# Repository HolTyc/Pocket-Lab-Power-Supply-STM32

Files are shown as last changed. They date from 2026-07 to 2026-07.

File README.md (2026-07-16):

# Pocket Lab Power Supply with STM32 MCU

THIS IS A FORK AND THE ORIGINAL VERSION IS HERE: https://github.com/BenMakesEverything/Pocket-Lab-Power-Supply/tree/main
A lab bench power supply, but pocket-sized and battery powered. (This repo is currently WIP)
The main MCU is STM32L031G6U6 for longer battery life.

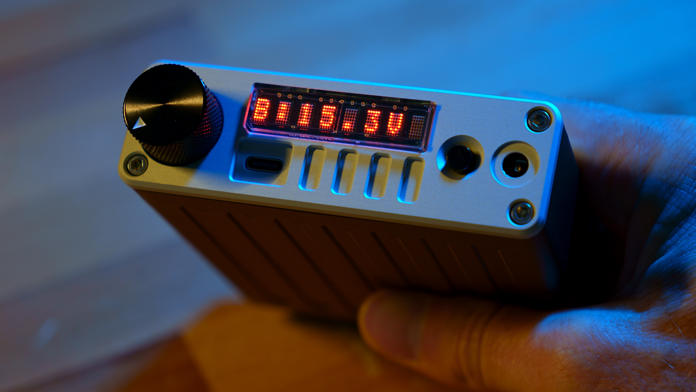
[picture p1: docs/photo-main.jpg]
Project photo


## What it is:

A 4S Lithium Ion-based Battery Bank which can act as a portable Lab-Bench Power Supply. Designed for use with 4S lithium-ion battery packs.

## Features:

- Adjustable output voltage and current limit
- Battery powered
- USB-C/PD charging
- 0.91 OLED display
- Open hardware and firmware

## Repository Structure:

- `/hardware` - PCB, schematic, BOM, Gerbers, CAD
- `/firmware` - MCU firmware and utilities
- `/docs` - build guide, diagrams, images, notes (WIP)

## Parts List

- Main PCB
- "Backpack" PCB for Display Module
- Display: HCMS-2971 or HCMS-2972 or HCMS-2973 or HCMS-2974 or HCMS-2975
- 4S 21700 Battery with integrated BMS (XH2.54mm connector) [LINK](https://www.foxbuying.com/21700-14-8v-4s1p-4500mah-rechargeable-power-lithium-battery-pack-with-customised-connetor.html)
- Faceplate
- 3D Printable Body
- 4x M3 Threaded Inserts
- 4x M3 Hex-head/socket bolts (16mm threaded portion)
- Plastic cap for button
- Encoder Knob [LINK](https://www.adafruit.com/product/5531)

## Documentation:

For common questions, see the [FAQ](docs/FAQ.md). This is a work in progress and I will add more.

The following flowchart gives an overview of the way the main components are connected.

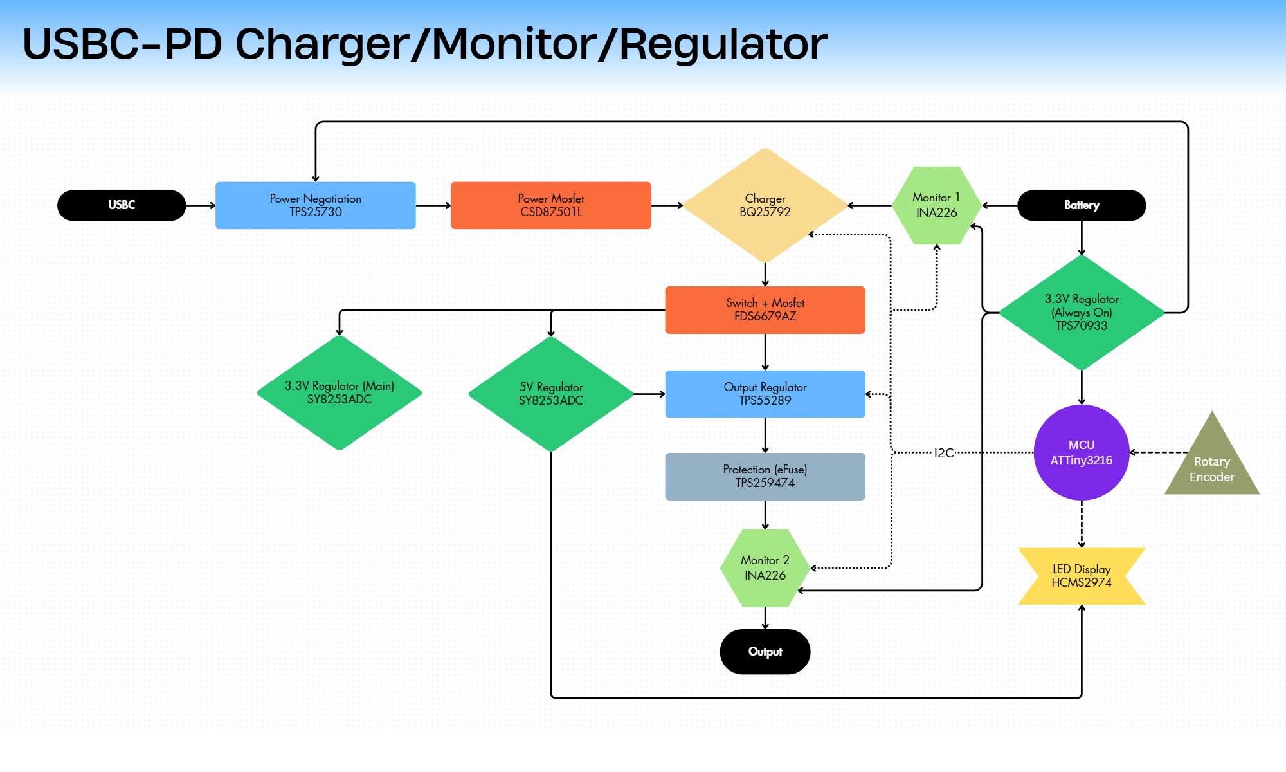
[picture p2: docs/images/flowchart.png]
Flowchart


## Safety Notice:

This project involves lithium-ion batteries and power electronics. Build and use at your own risk.

The PCB was designed for use with 4S battery packs. The BQ25792 will charge the pack up to 16.8V.

IF YOU WANT TO USE ANOTHER CELL CONFIGURATION YOU MUST CHANGE THIS! OTHERWISE THE CELLS WILL BE OVERCHARGED AND DAMAGED!

(Pin 20 "PROG" on the BQ25792 is the thing you need to adjust.)

YOU MUST USE A PACK THAT CONTAINS A BMS! THIS DESIGN DOES NOT INCLUDE ONE.

## License!

This project is licensed under the CERN Open Hardware Licence Version 2 - Strongly Reciprocal, CERN-OHL-S-2.0.

Unless otherwise stated, this applies to all hardware design files, firmware, software utilities, documentation, images, diagrams, CAD files, manufacturing files, and other project files in this repository.

Commercial use is allowed under the terms of the license. The project name, author name, logo, branding, and media identity are not licensed for use in marketing or endorsement without permission.

See `LICENSE.txt` for the full license text.

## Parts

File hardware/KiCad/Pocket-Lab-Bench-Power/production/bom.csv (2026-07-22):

Designator | Footprint | Quantity | Value | LCSC Part #
C1 | 0603 | 1 | 4.7uF/25V
C10, C7 | 0402 | 2 | 47nF
C11, C16, C17, C18, C21, C22, C23, C24, C25, C27, C28, C4 | 0805 | 12 | 10uF
C12, C37, C42, C44, C49, C5, C51, C56 | 0402 | 8 | 0.1uF
C13, C19, C20 | 0402 | 3 | 100nF
C14, C58, C6 | 0402 | 3 | 10uF
C15 | 0402 | 1 | 4.7 uF
C2, C3 | 0603 | 2 | 100nF/25V
C26, C39 | 0603 | 2 | 4.7uF
C29 | 0402 | 1 | 1nF
C30, C33, C70, C78 | 0603 | 4 | 100nF/50V
C31, C32, C34, C35, C74, C76, C80, C82 | 0603 | 8 | 22uF/10V
C36, C38 | 0603 | 2 | 10uF
C40, C45, C46, C47, C48, C50 | 0603 | 6 | 22uF
C43 | 0402 | 1 | 4.7nF
C52 | 0603 | 1 | 10u | C19702
C53, C63, C67 | 0402 | 3 | 100n | C1525
C55 | 0603 | 1 | 4.7nF
C57 | 0603 | 1 | 1uF
C60 | 1206 | 1 | 220uF | C412252
C62 | 0603 | 1 | 0.1uF
C64 | 0402 | 1 | 10n | C15195
C65, C66 | 0402 | 2 | 1u | C52923
C8, C9 | 0402 | 2 | 330pF
D2, D3 | DFN1006-2L-RD | 2 | PESD24VS1UL-N | C406227
D4 | SMB_L4.3-W3.6-LS5.4-RD | 1 | SMBJ24A_C224017 | C224017
D7 | 0603 | 1 | LED | C72038
FB1 | 0603 | 1 | FerriteBead | C1002
J1 | PinHeader_1x05_P2.54mm_Vertical | 1 | Conn_01x05_Pin
J2 | PinHeader_1x04_P2.54mm_Vertical | 1 | Conn_01x04_Pin | C2691448
J3 | Edge_Connect_6 | 1 | Conn_01x06_Pin
J4 | JST_PH_B2B-PH-K_1x02_P2.00mm_Vertical | 1 | Conn_01x02 | C495685
L1 | IND-SMD_L7.0-W6.6_MCW-0650-220 | 1 | 2.2uH | C5349701
L2, L3 | L_Sunlord_SWPA4020S | 2 | 2.2uH/4.3A | C3222957
L4 | IND-SMD_L7.5-W7.2-1 | 1 | 4.7uH | C3911513
MOSFET1 | SOIC8_751EB_ONS | 1 | FDS6679AZ | C116730
Q1 | PICOSTAR-YJG_TEX | 1 | CSD87501L | C2841784
R1, R11, R13, R37, R4, R8 | 0402 | 6 | 10K | C25744
R10 | 0603 | 1 | 30.1K 1%
R12, R15, R17, R21, R23, R25, R9 | 0603 | 7 | 0
R18 | 0603 | 1 | 21.5K/1%
R19, R38, R41 | 0603 | 3 | 4.7K/1%
R2, R33, R34 | 0402 | 3 | 10K
R28 | 0603 | 1 | 49.9K
R29, R51 | 0603 | 2 | 100K
R3 | 0603 | 1 | 100
R30, R32, R35 | 2512 | 3 | 0.01 | C840621
R31 | 0402 | 1 | 27K
R36 | 0603 | 1 | 560 1%
R5 | 0603 | 1 | 27K 1%
R57 | 0603 | 1 | 75K/1%
R58 | 0603 | 1 | 10K/1%
R6 | 0603 | 1 | 1K
R7 | 0603 | 1 | 5.23K 1%
S1 | XDCR_PEC12R-4220F-S0024 | 1 | PEC12R-4220F-S0024 | C18164805
SW1 | SW-TH_6P-L5.8-W5.8-P2.00-LS4.5-BL_1 | 1 | PS-5850A-6PL | C963201
TH1 | PinHeader_1x02_P2.54mm_Vertical | 1 | 103AT-2
TP10, TP7, TP8, TP9 | TestPoint_Pad_D1.5mm | 4 | TestPoint
U1 | WSON-6-1EP_2x2mm_P0.65mm_EP1x1.6mm | 1 | TVS2200DRV | C523793
U11 | AUDIO-TH_DC-S011A-D025-20A | 1 | DC-S011A-D025-20A | C7464915
U12 | VQFN-10_L2.0-W2.0-P0.45-TL | 1 | TPS259474ARPWR | C3662807
U13 | QFN-28_4x4mm_P0.5mm | 1 | STM32L031G6Ux | C96514
U15, U5 | TSOT-23-6 | 2 | SY8253ADC | C93736
U2 | RSM0032B-IPC_A | 1 | TPS25730SRSMR | C22390380
U3 | BQ25792 | 1 | BQ25792RQMR | C2862876
U4 | VSSOP-10_3x3mm_P0.5mm | 1 | INA226
U6 | RYQ0021A-MFG | 1 | TPS55289RYQR | C5942077
U7 | VSSOP-10_3x3mm_P0.5mm | 1 | INA226 | C49851
U8 | DMY0003A | 1 | ESD122DMYR | C1975871
U9 | DBV5_TEX | 1 | TPS70933DBVR | C89347
USB1 | USB-C-SMD_GT-USB-7051A | 1 | GT-USB-7051A | C2843970

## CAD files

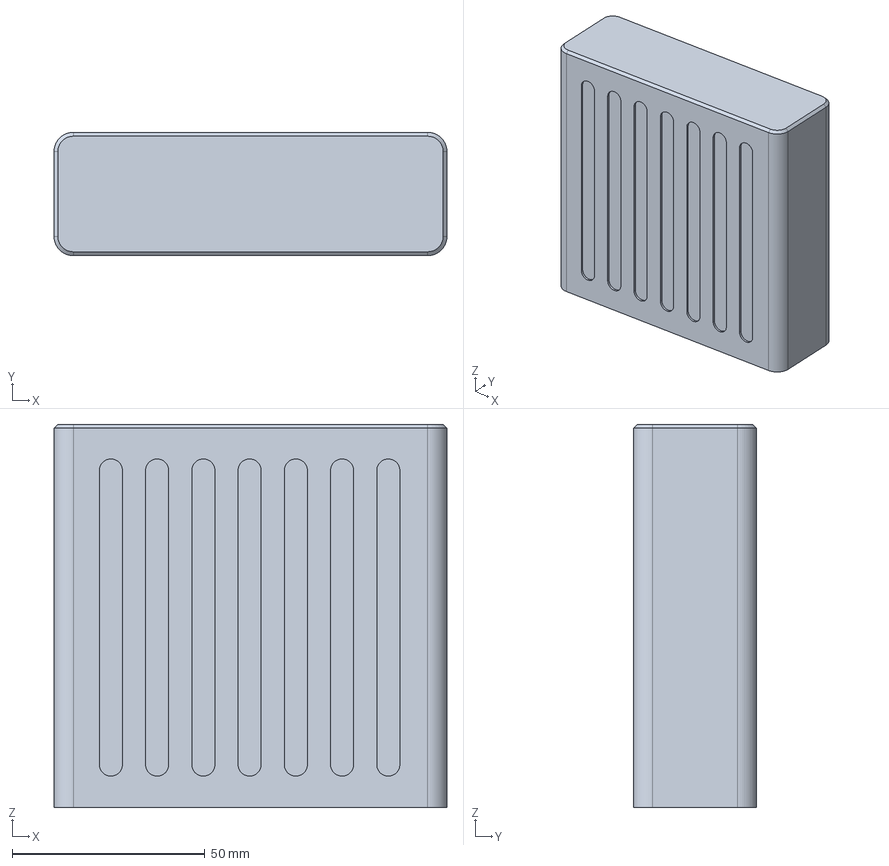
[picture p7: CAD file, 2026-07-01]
hardware/enclosure/Main-Case.step
102.0 x 32.0 x 99.5 mm

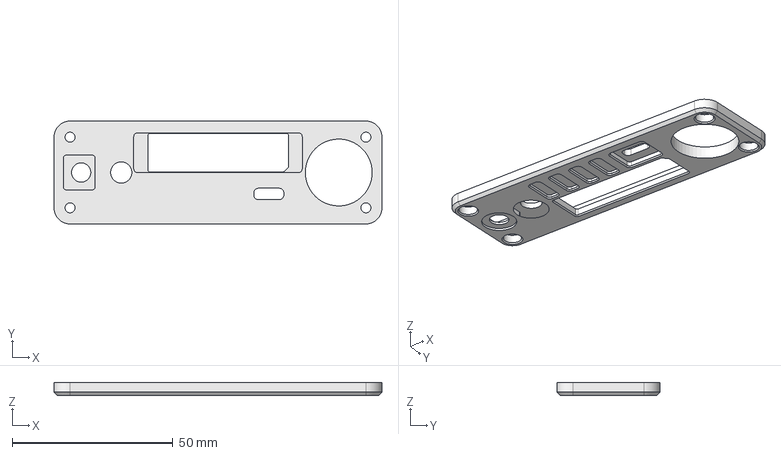
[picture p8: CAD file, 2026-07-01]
hardware/enclosure/Faceplate.step
102.0 x 32.0 x 4.00 mm

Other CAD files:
hardware/enclosure/Faceplate.stl
hardware/enclosure/Main-Case.stl

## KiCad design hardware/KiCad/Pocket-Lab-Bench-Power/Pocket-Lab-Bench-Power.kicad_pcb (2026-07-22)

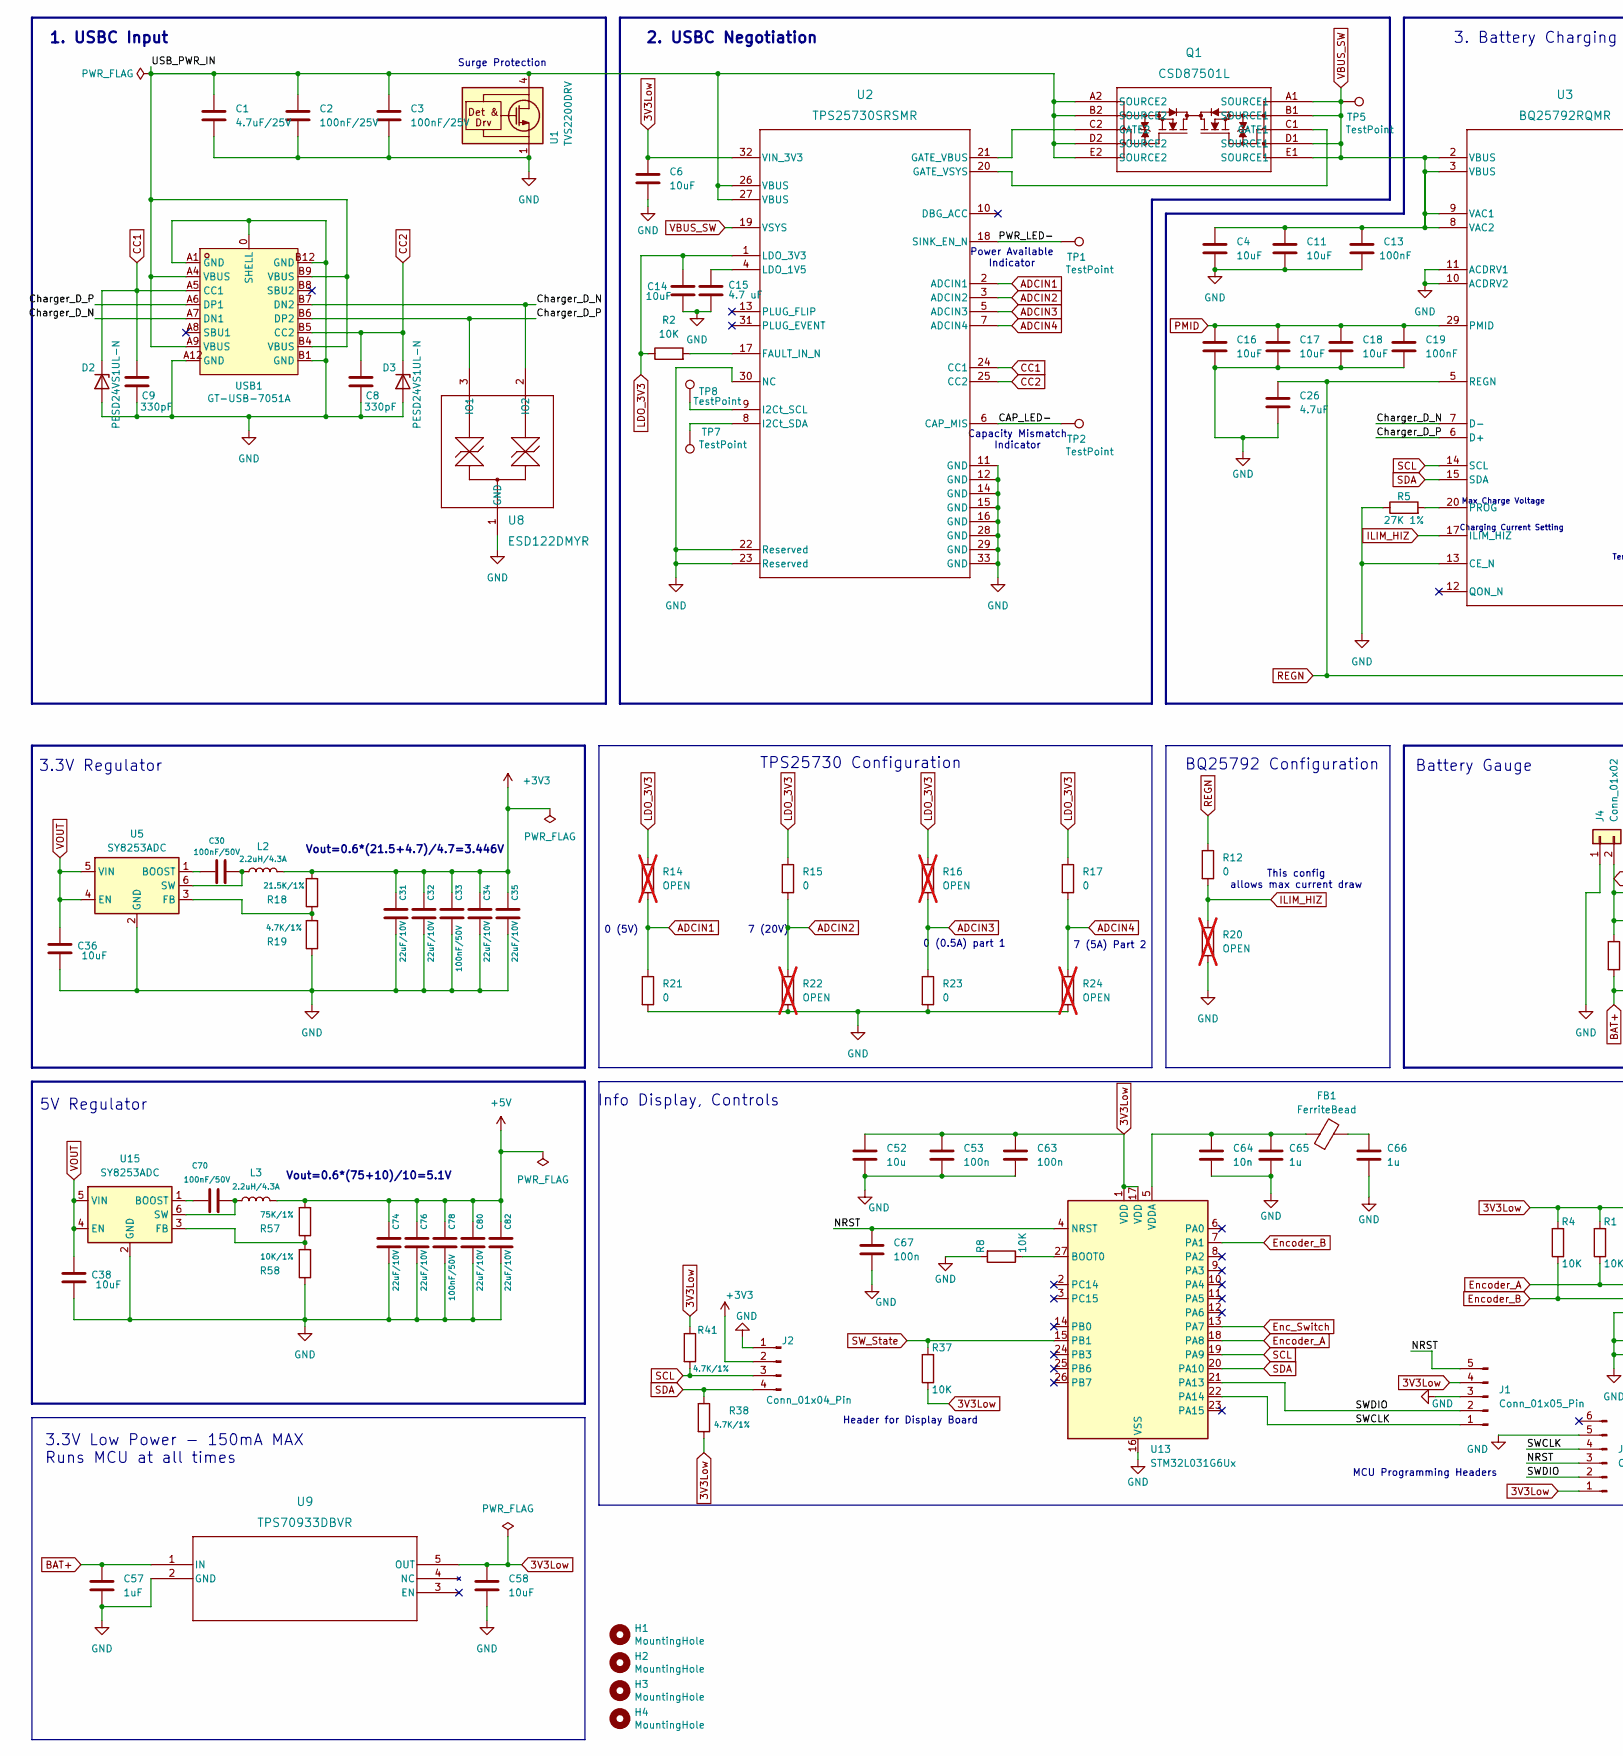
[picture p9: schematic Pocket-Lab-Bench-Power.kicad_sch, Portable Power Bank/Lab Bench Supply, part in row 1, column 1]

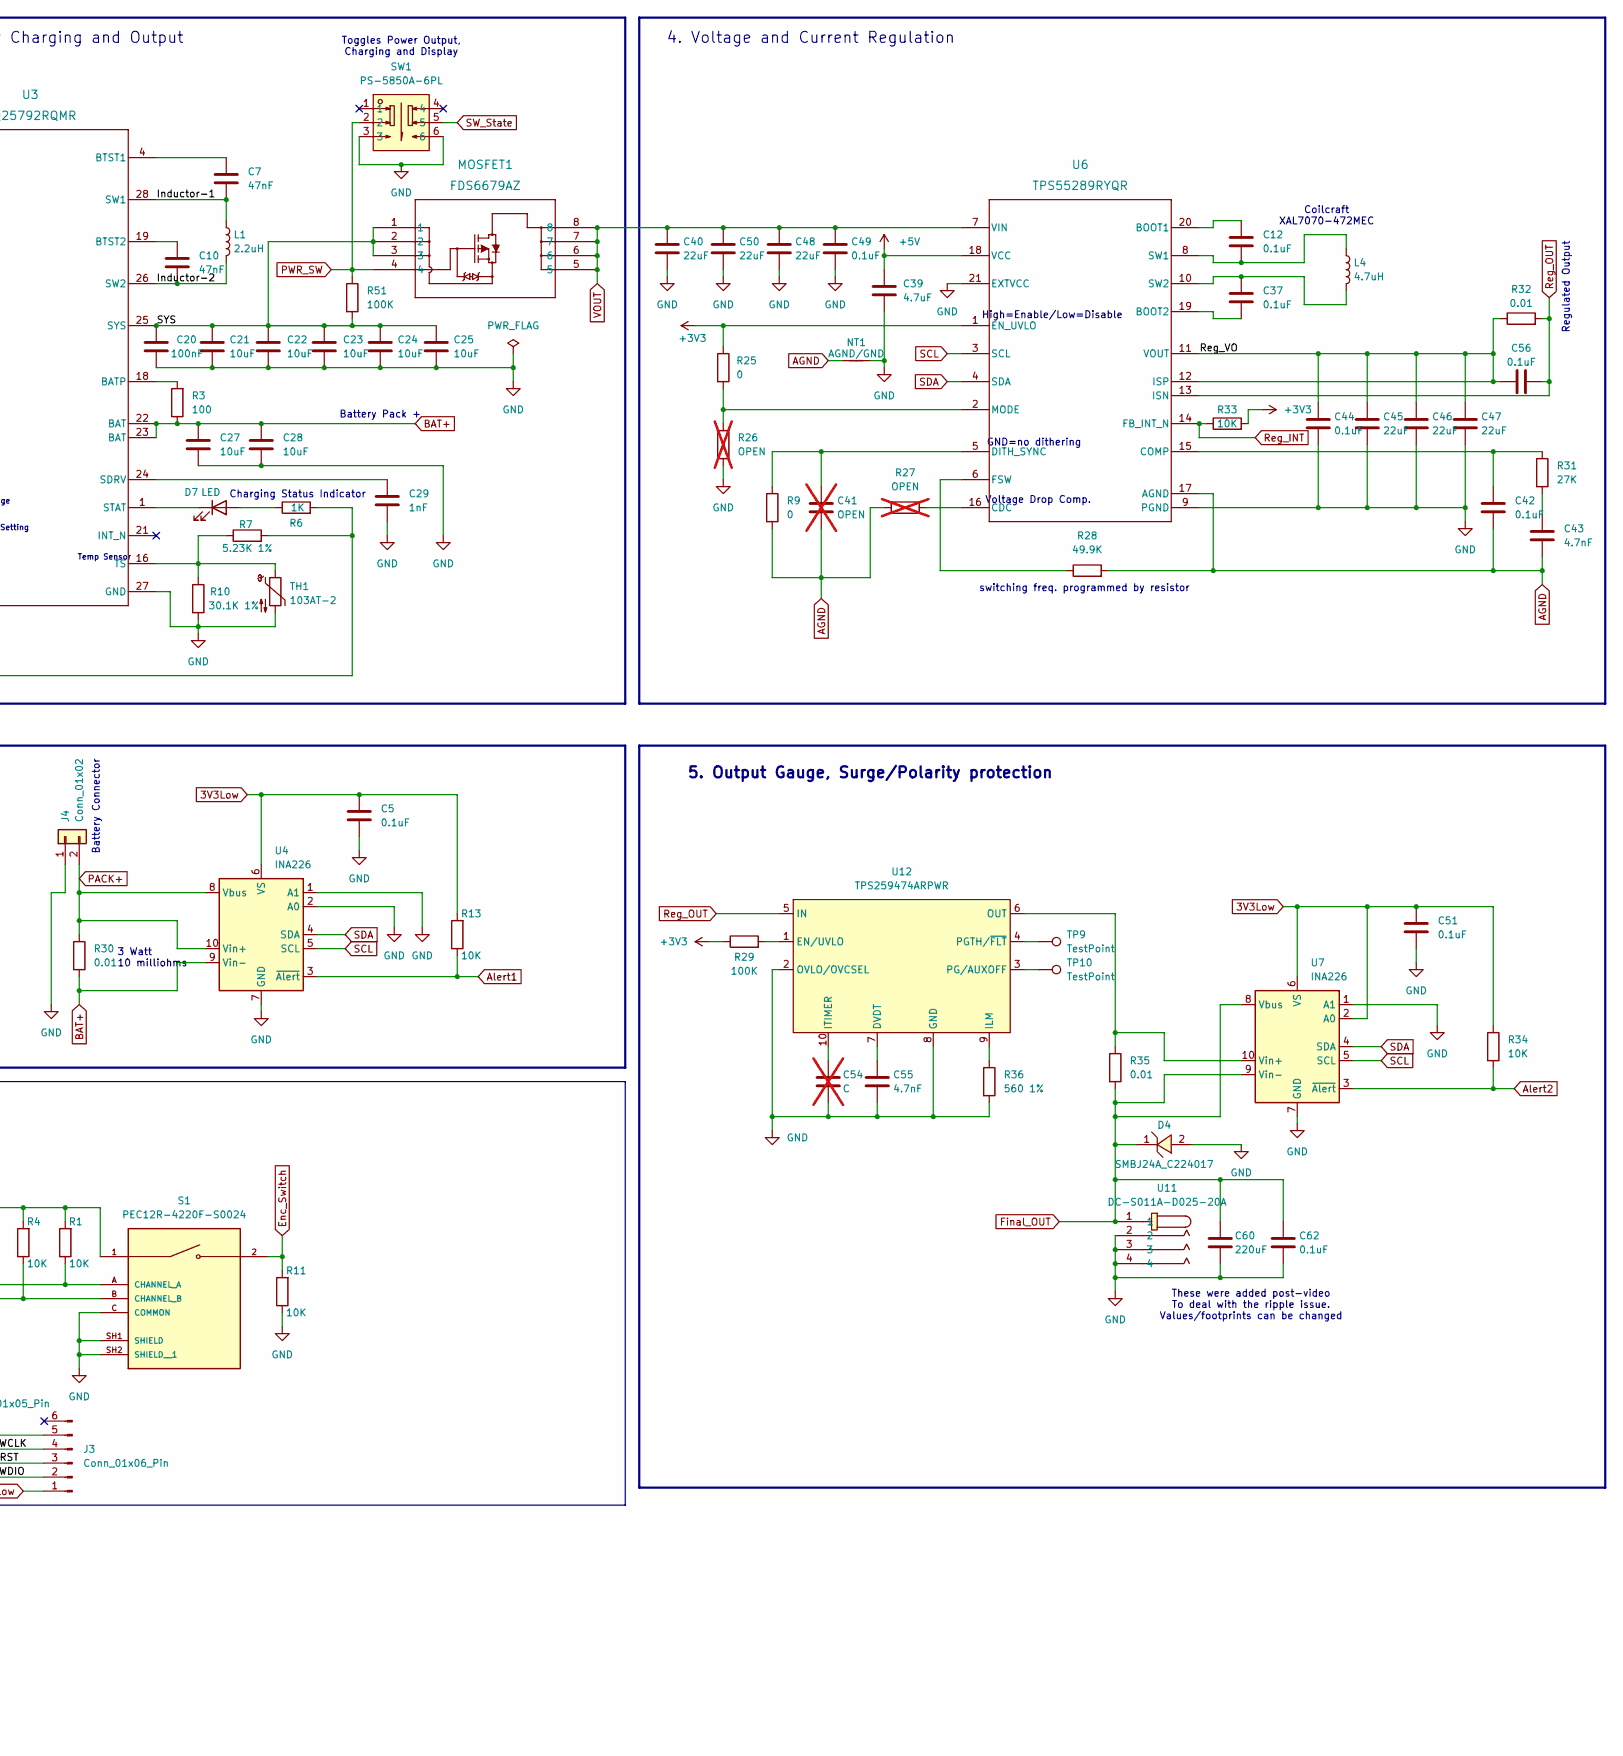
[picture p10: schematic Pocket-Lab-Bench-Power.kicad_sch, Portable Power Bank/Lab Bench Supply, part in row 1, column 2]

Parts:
C1: 4.7uF/25V; C_0603_1608Metric
C2, C3: 100nF/25V; C_0603_1608Metric
C4, C11, C16, C17, C18, C21, C22, C23, C24, C25, C27, C28: 10uF; C_0805_2012Metric
C5, C12, C37, C42, C44, C49, C51, C56: 0.1uF; C_0402_1005Metric
C6, C14, C58: 10uF; C_0402_1005Metric
C7, C10: 47nF; C_0402_1005Metric
C8, C9: 330pF; C_0402_1005Metric
C13, C19, C20: 100nF; C_0402_1005Metric
C15: 4.7 uF; C_0402_1005Metric
C26: 4.7uF; C_0603_1608Metric; Voltage Req 10V
C29: 1nF; C_0402_1005Metric
C30, C33, C70, C78: 100nF/50V; C_0603_1608Metric
C31, C32, C34, C35, C74, C76, C80, C82: 22uF/10V; C_0603_1608Metric
C36, C38: 10uF; C_0603_1608Metric
C39: 4.7uF; C_0603_1608Metric
C40, C45, C46, C47, C48, C50: 22uF; C_0603_1608Metric
C41: OPEN; C_0603_1608Metric; not fitted
C43: 4.7nF; C_0402_1005Metric
C52: 10u; C_0603_1608Metric; LCSC C19702
C53, C63, C67: 100n; C_0402_1005Metric; LCSC C1525
C54: C; C_0603_1608Metric; not fitted
C55: 4.7nF; C_0603_1608Metric
C57: 1uF; C_0603_1608Metric
C60: 220uF; C_1206_3216Metric; LCSC C412252
C62: 0.1uF; C_0603_1608Metric
C64: 10n; C_0402_1005Metric; LCSC C15195
C65, C66: 1u; C_0402_1005Metric; LCSC C52923
D2, D3: PESD24VS1UL-N; DFN1006-2L-RD; LCSC Part C406227
D4: SMBJ24A_C224017; SMB_L4.3-W3.6-LS5.4-RD; MPN SMBJ24A; LCSC Part C224017
D7: LED; LED_0603_1608Metric; LCSC Part C72038
FB1: FerriteBead; L_0603_1608Metric; LCSC C1002
H1, H2, H3, H4: MountingHole; MountingHole_3.2mm_M3
J1: Conn_01x05_Pin; PinHeader_1x05_P2.54mm_Vertical
J2: Conn_01x04_Pin; PinHeader_1x04_P2.54mm_Vertical; LCSC Part C2691448
J3: Conn_01x06_Pin; Edge_Connect_6
J4: Conn_01x02; JST_PH_B2B-PH-K_1x02_P2.00mm_Vertical; LCSC Part C495685
L1: 2.2uH; IND-SMD_L7.0-W6.6_MCW-0650-220; LCSC Part C5349701
L2, L3: 2.2uH/4.3A; L_Sunlord_SWPA4020S; LCSC Part C3222957
L4: 4.7uH; IND-SMD_L7.5-W7.2-1; LCSC Part C3911513
MOSFET1: FDS6679AZ; SOIC8_751EB_ONS; LCSC Part C116730
NT1: AGND/GND; NetTie-2_SMD_Pad0.5mm
Q1: CSD87501L; PICOSTAR-YJG_TEX; LCSC Part C2841784
R1, R4, R8, R11, R13, R37: 10K; R_0402_1005Metric; LCSC C25744
R2, R33, R34: 10K; R_0402_1005Metric
R3: 100; R_0603_1608Metric
R5: 27K 1%; R_0603_1608Metric
R6: 1K; R_0603_1608Metric
R7: 5.23K 1%; R_0603_1608Metric
R9, R12, R15, R17, R21, R23, R25: 0; R_0603_1608Metric
R10: 30.1K 1%; R_0603_1608Metric
R14, R16, R20, R22, R24, R26, R27: OPEN; R_0603_1608Metric; not fitted
R18: 21.5K/1%; R_0603_1608Metric
R19, R38, R41: 4.7K/1%; R_0603_1608Metric
R28: 49.9K; R_0603_1608Metric
R29, R51: 100K; R_0603_1608Metric
R30, R32, R35: 0.01; R_2512_6332Metric; LCSC Part C840621
R31: 27K; R_0402_1005Metric
R36: 560 1%; R_0603_1608Metric
R57: 75K/1%; R_0603_1608Metric
R58: 10K/1%; R_0603_1608Metric
S1: PEC12R-4220F-S0024; XDCR_PEC12R-4220F-S0024; PARTREV 07/21; LCSC Part C18164805
SW1: PS-5850A-6PL; SW-TH_6P-L5.8-W5.8-P2.00-LS4.5-BL_1; MPN PS-5850A-6PL; LCSC Part C963201
TH1: 103AT-2; PinHeader_1x02_P2.54mm_Vertical
TP1, TP2, TP5, TP7, TP8, TP9, TP10: TestPoint; TestPoint_Pad_D1.5mm
U1: TVS2200DRV; WSON-6-1EP_2x2mm_P0.65mm_EP1x1.6mm; LCSC Part C523793
U2: TPS25730SRSMR; RSM0032B-IPC_A; LCSC Part C22390380
U3: BQ25792RQMR; BQ25792; LCSC Part C2862876
U4: INA226; VSSOP-10_3x3mm_P0.5mm
U5, U15: SY8253ADC; TSOT-23-6; LCSC Part C93736
U6: TPS55289RYQR; RYQ0021A-MFG; LCSC Part C5942077
U7: INA226; VSSOP-10_3x3mm_P0.5mm; LCSC Part C49851
U8: ESD122DMYR; DMY0003A; LCSC Part C1975871
U9: TPS70933DBVR; DBV5_TEX; LCSC Part C89347
U11: DC-S011A-D025-20A; AUDIO-TH_DC-S011A-D025-20A; MPN DC-S011A-D025-20A; LCSC Part C7464915
U12: TPS259474ARPWR; VQFN-10_L2.0-W2.0-P0.45-TL; MPN TPS259474ARPWR; LCSC Part C3662807
U13: STM32L031G6Ux; QFN-28_4x4mm_P0.5mm; LCSC C96514
USB1: GT-USB-7051A; USB-C-SMD_GT-USB-7051A; MPN GT-USB-7051A; LCSC Part C2843970

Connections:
3V3Low: C5.1, C6.1, C51.1, C52.1, C53.1, C58.1, C63.1, J1.4, J3.1, R1.2, R4.2, R13.2, R34.1, R37.1, R38.2, R41.1, S1.1, U2.32 (VIN_3V3), U4.6 (VS), U7.2 (A0), U7.6 (VS), U9.5 (OUT), U13.1 (VDD), U13.17 (VDD)
+3V3: C31.2, C32.2, C33.1, C34.2, C35.2, J2.2, L2.2, R18.2, R25.1, R29.1, R33.2, U6.1 (EN_UVLO)
+5V: C39.1, C74.2, C76.2, C78.1, C80.2, C82.2, L3.2, R57.2, U6.18 (VCC)
/CAP_LED-: TP2.1 (1_1), U2.6 (CAP_MIS)
/Charger_D_N: U3.7 (D-), U8.2 (IO2), USB1.A7 (DN1), USB1.B7 (DN2)
/Charger_D_P: U3.6 (D+), U8.3 (IO1), USB1.A6 (DP1), USB1.B6 (DP2)
/Inductor-1: C7.2, L1.1, U3.28 (SW1)
/Inductor-2: C10.2, L1.2, U3.26 (SW2)
/NRST: C67.1, J1.5, J3.3, U13.4 (NRST)
/PWR_LED-: TP1.1 (1_1), U2.18 (SINK_EN_N)
/Reg_VO: C44.1, C45.1, C46.1, C47.1, C56.1, R32.1, U6.11 (VOUT), U6.12 (ISP)
/SWCLK: J1.1, J3.4, U13.22 (PA14)
/SWDIO: J1.2, J3.2, U13.21 (PA13)
/SYS: C20.1, C21.1, C22.1, C23.1, C24.1, C25.1, MOSFET1.1, MOSFET1.2, MOSFET1.3, R51.2, U3.25 (SYS)
/USB_PWR_IN: C1.1, C2.1, C3.1, Q1.A2 (SOURCE2), Q1.B2 (SOURCE2), Q1.D2 (SOURCE2), Q1.E2 (SOURCE2), U1.4 (IN), U1.5 (IN), U1.6 (IN), U2.26 (VBUS), U2.27 (VBUS), USB1.A4 (VBUS), USB1.A9 (VBUS), USB1.B4 (VBUS), USB1.B9 (VBUS)
ADCIN1: R14.2, R21.1, U2.2 (ADCIN1)
ADCIN2: R15.2, R22.1, U2.3 (ADCIN2)
ADCIN3: R16.2, R23.1, U2.5 (ADCIN3)
ADCIN4: R17.2, R24.1, U2.7 (ADCIN4)
AGND: C41.2, C42.2, C43.2, NT1.1, R9.2, R27.1, R28.2, U6.17 (AGND)
Alert1: R13.1, U4.3 (~Alert)
Alert2: R34.2, U7.3 (~Alert)
BAT+: C27.1, C28.1, C57.1, R3.1, R30.2, U3.22 (BAT), U3.23 (BAT), U4.9 (Vin-), U9.1 (IN)
CC1: C9.1, D2.1 (K), U2.24 (CC1), USB1.A5 (CC1)
CC2: C8.1, D3.1 (K), U2.25 (CC2), USB1.B5 (CC2)
Enc_Switch: R11.2, S1.2, U13.13 (PA7)
Encoder_A: R1.1, S1.A (CHANNEL_A), U13.18 (PA8)
Encoder_B: R4.1, S1.B (CHANNEL_B), U13.7 (PA1)
Final_OUT: C60.1, C62.1, D4.1, R35.2, U7.8 (Vbus), U7.9 (Vin-), U11.1
GND: C1.2, C2.2, C3.2, C4.1, C5.2, C6.2, C8.2, C9.2, C11.1, C13.2, C14.2, C15.2, C16.2, C17.2, C18.1, C19.2, C20.2, C21.2, C22.2, C23.2, C24.2, C25.2, C26.2, C27.2, C28.2, C29.2, C31.1, C32.1, C33.2, C34.1, C35.1, C36.2, C38.2, C39.2, C40.2, C44.2, C45.2, C46.2, C47.2, C48.2, C49.2, C50.2, C51.2, C52.2, C53.2, C54.2, C55.2, C57.2, C58.2, C60.2, C62.2, C63.2, C64.2, C65.1, C66.1, C67.2, C74.1, C76.1, C78.2, C80.1, C82.1, D2.2 (A), D3.2 (A), D4.2, J1.3, J2.1, J3.5, J4.1, NT1.2, R5.1, R8.2, R10.2, R11.1, R19.1, R20.2, R21.2, R22.2, R23.2, R24.2, R26.2, R36.2, R58.1, S1.C (COMMON), S1.SH1 (SHIELD), S1.SH2 (SHIELD__1), SW1.3, SW1.6, TH1.2, U1.1 (GND), U1.2 (GND), U1.3 (GND), U1.7 (GND), U2.11 (GND), U2.12 (GND), U2.14 (GND), U2.15 (GND), U2.16 (GND), U2.22 (Reserved), U2.23 (Reserved), U2.28 (GND), U2.29 (GND), U2.30 (NC), U2.33 (GND), U3.10 (ACDRV2), U3.11 (ACDRV1), U3.13 (CE_N), U3.27 (GND), U4.1 (A1), U4.2 (A0), U4.7 (GND), U5.2 (GND), U6.9 (PGND), U6.21 (EXTVCC), U7.1 (A1), U7.7 (GND), U8.1 (GND), U9.2 (GND), U11.2, U11.3, U11.4, U12.2 (OVLO/OVCSEL), U12.8 (GND), U13.16 (VSS), U13.28 (VSS), U15.2 (GND), USB1.0 (SHELL), USB1.A1 (GND), USB1.A12 (GND), USB1.B1 (GND), USB1.B12 (GND)
ILIM_HIZ: R12.2, R20.1, U3.17 (ILIM_HIZ)
LDO_3V3: C14.1, R2.1, R14.1, R15.1, R16.1, R17.1, U2.1 (LDO_3V3)
unnamed: C43.1, R31.2
unnamed: C66.2, FB1.2
unnamed: D7.2 (A), R6.1
unnamed: D7.1 (K), U3.1 (STAT)
unnamed: Q1.C1 (GATE1), U2.20 (GATE_VSYS)
unnamed: Q1.C2 (GATE2), U2.21 (GATE_VBUS)
unnamed: R2.2, U2.17 (FAULT_IN_N)
unnamed: TP8.1 (1_1), U2.9 (I2Ct_SCL)
unnamed: TP7.1 (1_1), U2.8 (I2Ct_SDA)
unnamed: C15.1, U2.4 (LDO_1V5)
unnamed: R3.2, U3.18 (BATP)
unnamed: C7.1, U3.4 (BTST1)
unnamed: C10.1, U3.19 (BTST2)
unnamed: R5.2, U3.20 (PROG)
unnamed: C29.1, U3.24 (SDRV)
unnamed: R7.1, R10.1, TH1.1, U3.16 (TS)
unnamed: C30.2, U5.1 (BOOST)
unnamed: R18.1, R19.2, U5.3 (FB)
unnamed: C30.1, L2.1, U5.6 (SW)
unnamed: C12.1, U6.20 (BOOT1)
unnamed: C37.2, U6.19 (BOOT2)
unnamed: R27.2, U6.16 (CDC)
unnamed: C42.1, R31.1, U6.15 (COMP)
unnamed: C41.1, R9.1, U6.5 (DITH_SYNC)
unnamed: R28.1, U6.6 (FSW)
unnamed: R25.2, R26.1, U6.2 (MODE)
unnamed: C12.2, L4.1, U6.8 (SW1)
unnamed: C37.1, L4.2, U6.10 (SW2)
unnamed: C55.1, U12.7 (DVDT)
unnamed: R29.2, U12.1 (EN/UVLO)
unnamed: R36.1, U12.9 (ILM)
unnamed: C54.1, U12.10 (ITIMER)
unnamed: R35.1, U7.10 (Vin+), U12.6 (OUT)
unnamed: TP9.1 (1_1), U12.4 (PGTH/~FLT)
unnamed: TP10.1 (1_1), U12.3 (PG/AUXOFF)
unnamed: R8.1, U13.27 (BOOT0)
unnamed: C64.1, C65.2, FB1.1, U13.5 (VDDA)
unnamed: C70.2, U15.1 (BOOST)
unnamed: R57.1, R58.2, U15.3 (FB)
unnamed: C70.1, L3.1, U15.6 (SW)
PACK+: J4.2, R30.1, U4.8 (Vbus), U4.10 (Vin+)
PMID: C16.1, C17.1, C18.2, C19.1, U3.29 (PMID)
PWR_SW: MOSFET1.4, R51.1, SW1.2
REGN: C26.1, R6.2, R7.2, R12.1, U3.5 (REGN)
Reg_INT: R33.1, U6.14 (FB_INT_N)
Reg_OUT: C56.2, R32.2, U6.13 (ISN), U12.5 (IN)
SCL: J2.3, R41.2, U3.14 (SCL), U4.5 (SCL), U6.3 (SCL), U7.5 (SCL), U13.19 (PA9)
SDA: J2.4, R38.1, U3.15 (SDA), U4.4 (SDA), U6.4 (SDA), U7.4 (SDA), U13.20 (PA10)
SW_State: R37.2, SW1.5, U13.15 (PB1)
VBUS_SW: C4.2, C11.2, C13.1, Q1.A1 (SOURCE1), Q1.B1 (SOURCE1), Q1.D1 (SOURCE1), Q1.E1 (SOURCE1), TP5.1 (1_1), U2.19 (VSYS), U3.2 (VBUS), U3.3 (VBUS), U3.8 (VAC2), U3.9 (VAC1)
VOUT: C36.1, C38.1, C40.1, C48.1, C49.1, C50.1, MOSFET1.5, MOSFET1.6, MOSFET1.7, MOSFET1.8, U5.4 (EN), U5.5 (VIN), U6.7 (VIN), U15.4 (EN), U15.5 (VIN)

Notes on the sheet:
Info Display, Controls
GND=no dithering
Battery Connector
4. Voltage and Current Regulation
Surge Protection
Voltage Drop Comp.
0 (5V)
switching freq. programmed by resistor
Battery Pack +
Charging Status Indicator
7 (20V)
BQ25792 Configuration
Temp Sensor
3.3V Regulator
Header for Display Board
Coilcraft XAL7070-472MEC
1. USBC Input
2. USBC Negotiation
TPS25730 Configuration
5. Output Gauge, Surge/Polarity protection
Regulated Output
3.3V Low Power - 150mA MAX Runs MCU at all times
3. Battery Charging and Output
7 (5A) Part 2
0 (0.5A) part 1
Capacity Mismatch Indicator
Charging Current Setting
These were added post-video To deal with the ripple issue. Values/footprints can be changed
Power Available Indicator
MCU Programming Headers
This config allows max current draw
Toggles Power Output, Charging and Display
3 Watt 10 milliohms
Max Charge Voltage
5V Regulator
Vout=0.6*(21.5+4.7)/4.7=3.446V
High=Enable/Low=Disable
Battery Gauge
Vout=0.6*(75+10)/10=5.1V

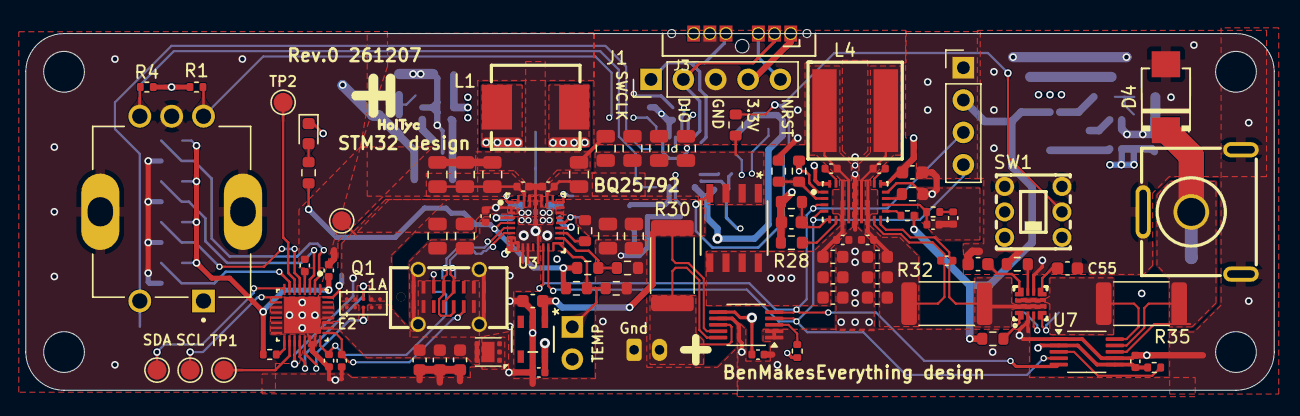
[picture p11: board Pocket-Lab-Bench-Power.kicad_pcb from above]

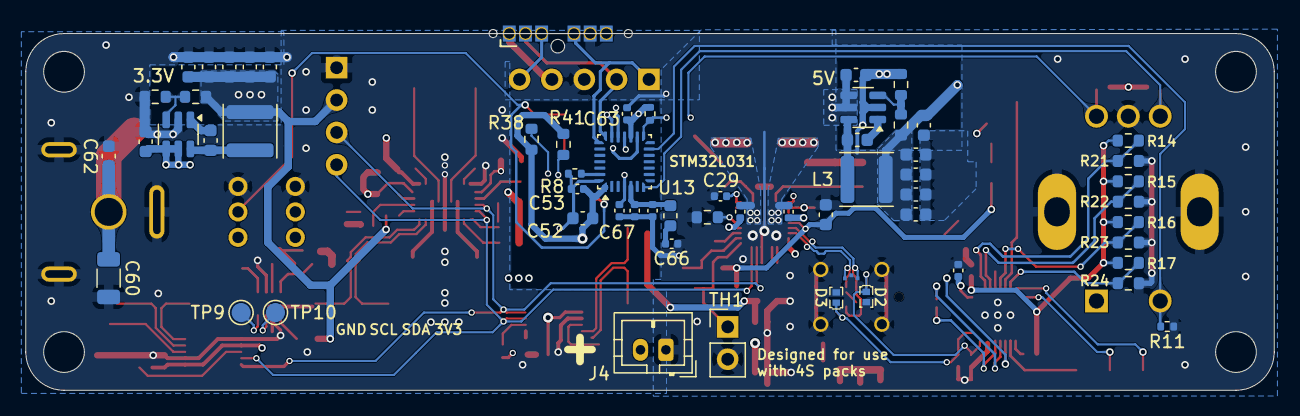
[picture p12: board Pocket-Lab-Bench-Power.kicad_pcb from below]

Board: 4 copper layers, 98.0 x 28.0 mm, 157 parts (59 on the bottom side), 83 nets.

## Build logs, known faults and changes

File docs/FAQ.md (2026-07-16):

# Frequently Asked Questions

## Q: What is the maximum output voltage?

A: Short Answer: 20V. 

Long Answer: Theoretical max allowed by the regulator is 22V. However I have it capped at 20V in software. Due to the nature of the compensation system on the chip, it falls slightly short of 22V even when set to that, so I soft-limited it.

## Q: What is the maximum current it can supply?

A: Software limited to 5A. Theoretical max is 6.35, but the system was not designed for high-current loads. (In fact, 5A is probably too high for extended use at higher voltages). I advise against powering anything beyond about 50 Watts.

## Q: Can it supply power via the USBC port?

A: No, the USB C port is for charging only.

## Q: Can it charge while being used/powering something?

A: Yes (if the load is less than the charging current)

## Q: What is the battery life?

A: That depends on what you are powering! Capacity is 4500mAh.

## Q: Can the firmware be modified?

A: Yes! It is simply written in Arduino.

## Q: How do I program the ATTiny?

A: UPDI. If the battery is connected, all you need to do is connect the UPDI pin through a resistor to an Arudino that has the UPDI programmer flashed to it, as well as the ground pin of the PCB to the arduino's ground pin.

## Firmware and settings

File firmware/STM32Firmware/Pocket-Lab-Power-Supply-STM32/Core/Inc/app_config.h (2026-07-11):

/* Pocket Lab-Bench Power Supply - STM32L031G6U6 port
 *
 * All user-adjustable settings live in this file: GPIO assignments,
 * I2C addresses, voltage/current limits and display behaviour.
 *
 * Ported from the original ATtiny3216 Arduino sketch
 * (firmware/Pocket-Lab-Bench-Power-V1.ino) by "Ben Makes Everything".
 *
 * Display: 0.91" 128x32 SSD1306 OLED on the shared I2C1 bus.
 */

#ifndef APP_CONFIG_H
#define APP_CONFIG_H

#include "stm32l0xx_hal.h"

/* ----------------------------------------------------
 * GPIO assignments
 * ----------------------------------------------------
 * These pins are plain GPIO inputs and can be moved to any free pin;
 * App_Init() configures them from these defines (the CubeMX settings
 * are overridden). Remember to also enable the port clock if you move
 * a pin to a port other than GPIOA/GPIOB (see app_gpio_init in app.c).
 *
 * NOT freely movable:
 *   - Encoder A/B: fixed to TIM2_CH1 = PA8 (AF5) and TIM2_CH2 = PA1 (AF2),
 *     because the hardware quadrature decoder of TIM2 is used.
 *   - I2C: fixed to I2C1 on PA9 (SCL) / PA10 (SDA).
 * Change those in CubeMX (.ioc) if the board layout ever changes.
 */

/* Power switch sense: HIGH = main output OFF, LOW = main output ON */
#define SWITCH_STATE_GPIO_PORT      GPIOA
#define SWITCH_STATE_GPIO_PIN       GPIO_PIN_7
#define SWITCH_STATE_GPIO_PULL      GPIO_PULLUP

/* Rotary encoder push button, active LOW */
#define ENC_SW_GPIO_PORT            GPIOB
#define ENC_SW_GPIO_PIN             GPIO_PIN_1
#define ENC_SW_GPIO_PULL            GPIO_PULLUP

/* Enable internal pull-ups on the encoder A/B timer pins (PA8/PA1).
 * Set to 0 if the PCB has external pull-ups. */
#define ENC_AB_INTERNAL_PULLUPS     1

/* ----------------------------------------------------
 * Encoder behaviour
 * ----------------------------------------------------
 * TIM2 runs in encoder mode TI1 (counts both edges of channel A only),
 * which gives 2 counts per full quadrature cycle. A PEC12R-style encoder
 * produces one full cycle (4 transitions) per detent -> 2 counts/detent.
 */
#define ENCODER_COUNTS_PER_DETENT   2
/* The original firmware reversed the raw direction so that clockwise
 * increases the value. Set to 0 if your encoder turns the wrong way. */
#define ENCODER_REVERSE_DIRECTION   1

#define BUTTON_DEBOUNCE_MS          40u

/* ----------------------------------------------------
 * SSD1306 OLED (0.91", 128x32) settings
 * ---------------------------------------------------- */
#define OLED_I2C_ADDR               0x3C  /* 7-bit address */
#define OLED_WIDTH                  128
#define OLED_HEIGHT                 32

/* ----------------------------------------------------
 * TPS55289 buck-boost converter settings
 * ---------------------------------------------------- */
#define TPS_ADDR_1                  0x74
#define TPS_ADDR_2                  0x75

/* 0x31 = longest OCP response delay (~12.3 ms), 2.5 mV/us VOUT slew */
#define TPS_VOUT_SR_VALUE           0x31
/* 0x82 = output enabled, forced-PWM enabled */
#define TPS_MODE_VALUE              0x82

/* ----------------------------------------------------
 * INA226 current monitor settings
 * ---------------------------------------------------- */
#define INA_BATTERY_ADDR            0x40  /* 7-bit, binary 1000000 */
#define INA_OUTPUT_ADDR             0x41  /* 7-bit, binary 1000001 */

/* Shunt resistor values: 10 milliohms = 0.010 ohms */
#define BATTERY_SHUNT_OHMS          0.01f
#define OUTPUT_SHUNT_OHMS           0.01f

#define INVERT_BATTERY_CURRENT      0
#define INVERT_OUTPUT_CURRENT       0

#define SHOW_DRAW_AS_POSITIVE       1

/* ----------------------------------------------------
 * Charging display settings
 * ----------------------------------------------------
 * If enabled, a "CHG" indicator is shown while net current flows
 * into the battery. */
#define SHOW_CHARGING_STATUS        1
#define BATTERY_CHARGING_CURRENT_IS_POSITIVE  0
/* Ignore small currents/noise around zero so the display does not flicker */
#define BATTERY_CHARGING_CURRENT_THRESHOLD_A  0.050f  /* 50 mA */

/* ----------------------------------------------------
 * Output voltage settings
 * ---------------------------------------------------- */
/* Initial startup voltage - the device powers on with this value (in mV) */
#define STARTUP_MV                  5000

/* Remember the last voltage set before power-off?
 * 0 = default to STARTUP_MV
 * 1 = save the selected voltage to the L031 data EEPROM on power-off
 *     and restore it on startup */
#define REMEMBER_OUTPUT_VOLTAGE_ON_POWER_OFF  0

/* Regulator limits: TPS55289 range is 800 mV .. 22000 mV */
#define MIN_MV                      1000
#define MAX_MV                      20000
#define STEP_MV                     100
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

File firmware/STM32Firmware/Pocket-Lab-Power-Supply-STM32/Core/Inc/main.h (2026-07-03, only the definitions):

#define SW_State_Pin GPIO_PIN_7
#define SW_State_GPIO_Port GPIOA
#define Enc_switch_Pin GPIO_PIN_1
#define Enc_switch_GPIO_Port GPIOB

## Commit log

2026-07-01 Added arduino file
2026-07-03 Init of STM32 fork
2026-07-03 Firmware + schema
    I added STM32 project (version of cubeide 2.2). Added STM32 to schema
    [Pocket-Lab-Bench-Power.kicad_pcb, Pocket-Lab-Bench-Power.kicad_sch]
2026-07-03 PCB routing #1
    [Pocket-Lab-Bench-Power.kicad_pcb, Pocket-Lab-Bench-Power.kicad_sch]
2026-07-05 Added screenshots of PCB layers
2026-07-05 added flowchart image to docs
2026-07-11 Translating arduino to STM32
2026-07-16 All routing done
    [Pocket-Lab-Bench-Power.kicad_pcb, Pocket-Lab-Bench-Power.kicad_sch, bom.csv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]
2026-07-22 EdgeConnect for programming STM32
    [Pocket-Lab-Bench-Power.kicad_pcb, Pocket-Lab-Bench-Power.kicad_sch, bom.csv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]

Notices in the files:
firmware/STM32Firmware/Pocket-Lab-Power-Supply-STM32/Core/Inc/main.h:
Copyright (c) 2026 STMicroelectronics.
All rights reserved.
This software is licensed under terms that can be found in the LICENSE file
